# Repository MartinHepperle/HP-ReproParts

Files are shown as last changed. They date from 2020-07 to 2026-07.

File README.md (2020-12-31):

<h1>HP-ReproParts</h1>
<p>This repository collects my 3D printable parts for computers.
The focus is mainly on Hewlett Packard computers.
</p>
<p>Most of these parts have been printed on my low cost hobby printer "Anycubic Mega 3D" in PLA.
Before I owned it, I had sent the STL files to commercial 3D printing services to obtain parts in very good quality and in materials unavailable for hobby printers, e.g. very strong sintered nylon.
</p>

<p>The data is available in binary STL format, which can be used by all commercial printing services.
For your hobby printer you have to process it by your favorite slicing software (e.g. Cura) to produce the required toolpath files in GCODE format with the preferred settings for your printer.
</p>
<p>I have spent a considerable amount of time to create these models and am happy to provide these parts for hobby purposes.
You can use these models for any non-commercial purposes, but not sell the models or parts made from them for profit.
All parts will require some sort of rework and assembly. No batteries included.
I cannot guarantee that these parts are fit for any purpose, so use at your own risk.
These parts were created for replacing broken or missing parts of obsolete computers and peripherals for hobby purposes. They may violate safety regulations and disturb your good taste. Consume with a grain of salt and brain.
</p>

<p>Note to collectors: these parts are different enough from genuine spare parts so that they cannot be mistaken for fakes.
</p>

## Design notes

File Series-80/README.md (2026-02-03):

<h1>Parts for Series-80 Computers (85, 86, 87, 9915)</h1>

<ul>
  <li>Case for interface modules, PRM-85 module or other new developments (what about that new color graphics board you wanted to develop?),</li>
  <li>EPROM-Drawer-Bot and EPROM-Drawer-Top make a module case for a reporduction EPROM drawer, using the slightly modified PCB created by Tony Cox.</li>
  <li>Case for the EBTKS board with two different upper shells - select one according to your taste</li>
  <li>Replacement plungers for Series-80 keyboards (requires UV-resin printer). This model is for the plungers with 4 thin "feet" extending downwards.</li>
</ul>

<h2>Notes</h2>
<p>
I use small M 2.5 screws with threaded brass inserts to close the cases. Metal washers can be glued into the recesses to provide a stronger surface for the screw heads.
Inserts and washers can be glued in with steel filled epoxy in double syringes which gives a stronger and harder bond than the more flexible clear epoxy glues. Ideally, the brass inserts can simply be pressed into the holes without glue and secured with a few drops of superglue.
Self tapping screws do not go well with PLA - maybe you have better luck or use ABS.
</p>
The EPROM-Drawer module case is about 10 mm longer than the standard module case. The reason for this: unfortunately, the PCB layout created by Tony Cox is a bit larger than the original layout and I do not have a possibility to modify it easily.
Also portions of the the side edges of the PCB have to be milled away to make the PCB fit into the module case. All this must be done before placing components on the board, of course.
The openings in the top allow for using standard sockets and also for seeing which EPROMs are installed. The original drawer uses semi-buried sockets which seem to be unobtainium today.
</p>
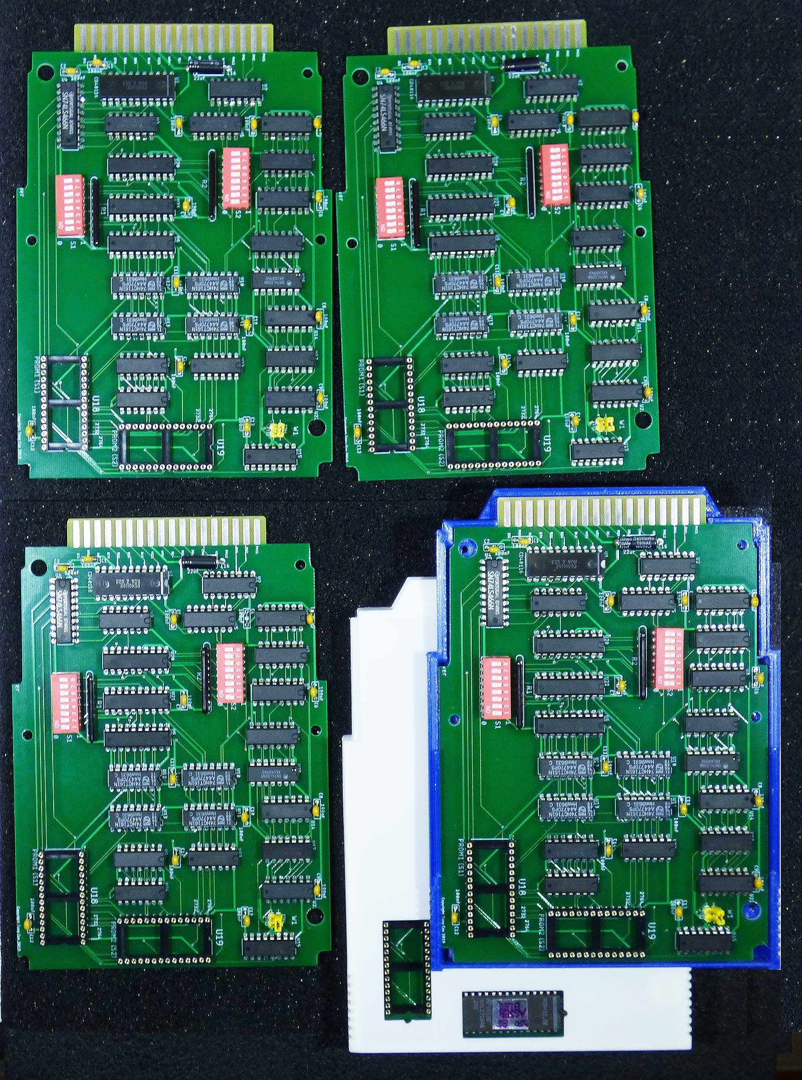
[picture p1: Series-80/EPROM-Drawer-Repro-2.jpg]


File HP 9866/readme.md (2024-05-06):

These models are rear bumpers for the HP 9866 printer and some HP 98x0 computers.

The original parts often become brittle and crumble into pieces.
You can print them in hard PLA or, even better, use a flexible material like TPU (shore 58 or similar).

Printing them "upside down" (with the rim pointing upwards) eliminates the need for support structures.

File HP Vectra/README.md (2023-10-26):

These parts can be used to install a 3.5 inch flexible disk drive into the early HP-Vectra PC drive cage, using sliding side rails.
The small rectangular block can be glued onto the rail with rubber cement, allowing for adjusting the depth position to match the front bezel.
If necessary, it can be broken lose to remove the disk drive.
I also glued strips of cardboard to the side of the rails to achieve smooth motion with a bit of friction.

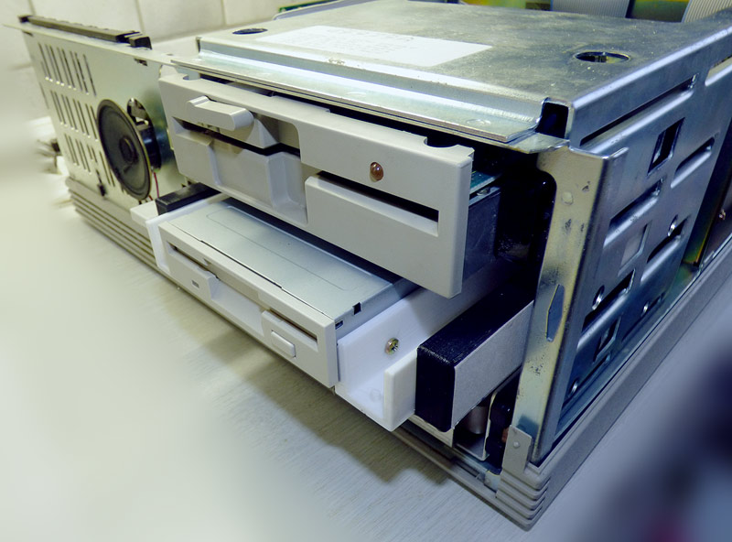
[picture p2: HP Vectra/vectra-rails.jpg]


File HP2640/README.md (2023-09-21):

<h1>Parts for HP Terminals of the 264x Series.</h1>
<ul>
  <li>cover for keyboard switches</li>
  <li>cable hood for the serial interface cable</li>
</ul>

<h2>Cable Hoods:</h2>
I usually glue the cables into these hoods after testing them, because screws do not hold well in the relatively soft PLA material.
Also, it is simple to make another one, if needed. 
For the cables I often use ready made serial or parallel printer cables with 25 or 36 wires and replace the connectors.
This is cheaper than buying cable by the meter and one connector is already in place.

<h2>HP 2640 Keyboard Cover</h2>
When printed in PLA, the nose of the retention clip may break if it is bent too much. 
Use a file or sharp knife to shorten it so that the cover is held in place without overstressing the part.
If the clip breaks, cyanacrylate superglue may be your friend.

<h2>Color</h2>
I printed the cover in white and painted it later.
The keyboard cover can be painted with plastic model paint like Testors, Revell or what else. 
They offer many gray/tan tones to match your more or less yellowed keyboard.

<h2>Surface Quality</h2>
3D printing usually leaves a fine structure on the surface. You may want to experiment with layer thickness and extruder temperature.
If you are a perfectionist, you can apply multiply cycles of polyester putty or spray-on filler followed by wet sanding to create a smooth surface.
When printing in ABS, it might be possible to smooth the surface and close tiny gaps by applying acetone, but this is a bit on the risky side of life.

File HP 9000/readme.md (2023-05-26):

HP 9836 color monitor cable hood
================================
For building a replacement for the monitor cable I used a VGA cable with shielded R, G, B wires and these shells.
After testing, both halves were simply glued together.

HP 9000 DIO Board Lever
=======================
Suitable for do-it your self DIO-I boards or for replacing broken handles.

HP 9836 monitor locking plate handle
====================================
The HP 9836 monitor is locked to the computer case by a sliding aluminum plate with two square plastic handles.
The material of these handles becomes brittle and often their corners break, leaving only ugly fragments of the handles.
You can remove the nickel plated brass rivets after thinning their hollow ends by drilling with a 5-6 mm drill bit to about 1 mm depth.
This just removes part of the widened end so that the rivets can be pushed out, e.g. with a 3 mm steel pin and a hammer.
Then you can mount the new handles and install the rivets again simply by pressing them in using a vise.
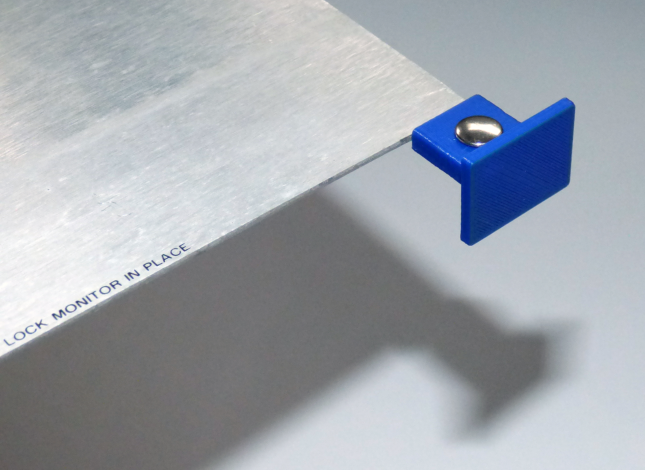
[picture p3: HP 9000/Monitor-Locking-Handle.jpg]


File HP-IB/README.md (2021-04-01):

<h1>Parts for HP-IB Devices</h1>
<ul>
<li>Case for the HP85Disk PCB</li>
</ul>

<em>The HP-logo was created with a vinyl cutter which was found on the curb. 
  Only the repair of the broken power connector and a set of new knifes was necessary. Plus some investigation about the almost forgotten Houston Instruments DMPL plotter language to make it useful again...</em>

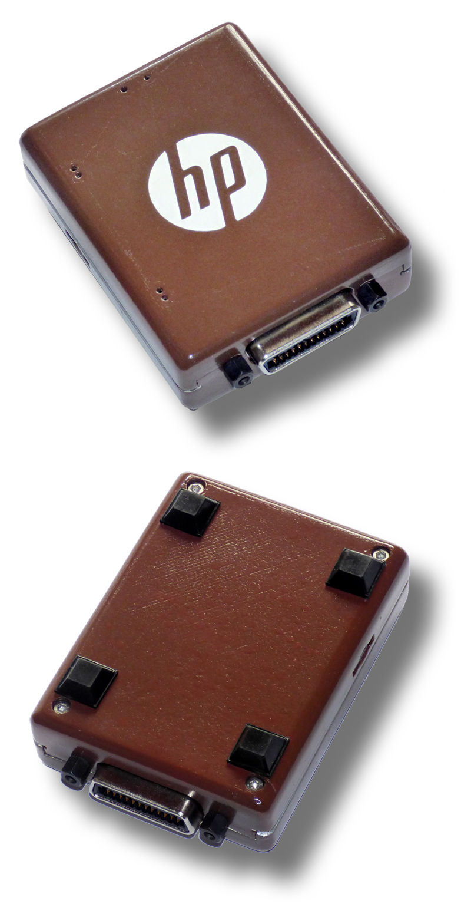
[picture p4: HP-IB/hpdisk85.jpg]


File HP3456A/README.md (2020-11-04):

Often you receive test equipment without the mounting brackets ("ears"). These can be found on E-Bay, but here in Europe they are rarely offered.
Therefore I tried to make my own replacements.

I have used them for mounting some HP test equipment, like the 3456A voltmeters in a small 19" rack.
All parts are massive (i.e. no hollow internal structure) to provide sufficient strength, thus take about 4-5 hours to print on a hobby printer.
You should check whether the weight of your device can be properly supported.
Often it may be better to produce similar parts from sheet metal or "L"-type bar stock.

The front brackets will suit many other HP devices. I did not bother to add handles to these parts.

The rear brackets were needed to support the deep boxes, which overhang the rear end of my short rack.
They are probably not useful for other applications.

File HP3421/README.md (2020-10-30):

<h1>Parts for the HP 3421 Data Acqusition System</h1>
<ul>
  <li>rear cover</li>
  <li>cable strain relief clamp</li>
</ul>
Both are held in place by M3 screws (cover: 10 mm, clamp: 16 mm). A strip of foam should be glued to the cover so that the wires are pressed into the foam by the ridge on the clamp.

These data acqusition systems have 3 slots for plug-in boards and sometimes the covers and cable clamps are missing.
Note that some boards also use specific screw terminal blocks (e.g. the relais multiplexer) while others use simpe edge connectors (the digital I/O board). I do not have a solution for these missing terninal blocks.

<image src="https://github.com/MartinHepperle/HP-ReproParts/blob/master/HP3421/HP-3421-cover-and-clamp.jpg"></image>

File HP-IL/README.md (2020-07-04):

<h1>Parts for the HP-IL Loop</h1>

<ul>
<li>Individual connectors for creating cables</li>
<li>Twin connector pair for building into devices</li>
</ul>
The "joined" parts are several small parts joined by spruces to form a single part. 
Many commercial 3D print services do not handle a set of small parts - they want a single part to simplify handling.

<p>
  Note that manufacturing these small connectors requires more parts (connector pins) and some delicate assembly work.
  More details can be found on https://www.MH-AeroTools.de/hp.  
  </p>

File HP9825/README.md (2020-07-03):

<h1>Parts for the HP 9825 Desktop Calculator</h1>
<ul>
  <li>ROM module case.</li>
  <li>rear cover (may need some metalwork to replace fine nose at bottom.</li>
</ul>

These parts can be used to build a case for a custom ROM or ROM replacement board.

The rear cover must be glued or riveted together and some fine tuning will be necessary to make the retention clip fit into the case. Maybe a small metal or hard plastic strip should be added to make it fit into the thin slot in the foam plastic case of the 9825.

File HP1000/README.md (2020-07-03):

<h1>Parts for HP 1000 Computer Systems</h1>

<ul>
  <li>edge connector hoods for different connector types</li>
</ul>

These were made for hooking up cables to I/O boards of the HP 1000 A-Series.

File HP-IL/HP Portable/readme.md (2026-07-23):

These files demonstrate how to use the HP-IL interface of the HP 110 and the Portable Plus from Microsoft BASIC.
The module works with the ROM-based BASIC interpreter and should also be usable with the disk-based GWBASIC interpreter for the HP Portable.
A binary module with several functions is loaded and can be used to interact with HP-IL devices on the loop.

Assemble on a PC with e.g. DOS-BOX
--------------------
The assembler source in HPIL.ASM can be assembled with a batch file like GO.BAT and the resulting binary file can be converted into a BASIC program (in ASCII format) by using the Python script BINtoHEX.py.
This script creates code to load the binary from DATA statements and appends an example program for talking to a digital voltmeter. The loader also saves the machine code as a binary file which can later be loaded with BLOAD to speed the loading proces up.

Transfer to the Portable
--------------------
For transferring the ASCII file to the portable a serial interface and the bult in or one of the ROM-based terminal programs can be used.

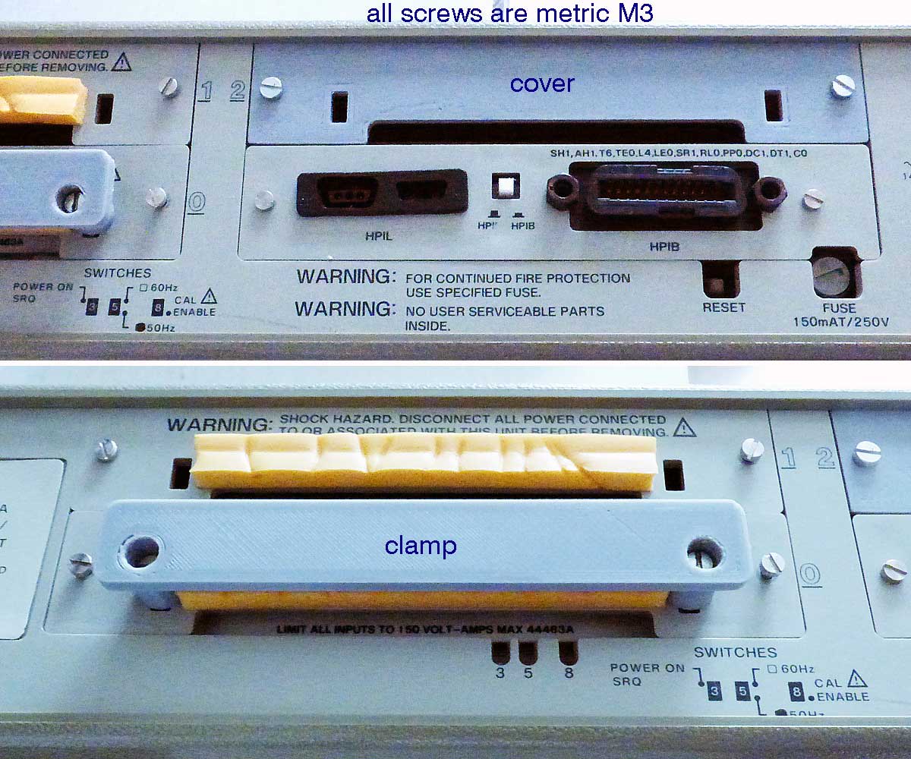
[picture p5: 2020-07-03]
HP3421/HP-3421-cover-and-clamp.jpg

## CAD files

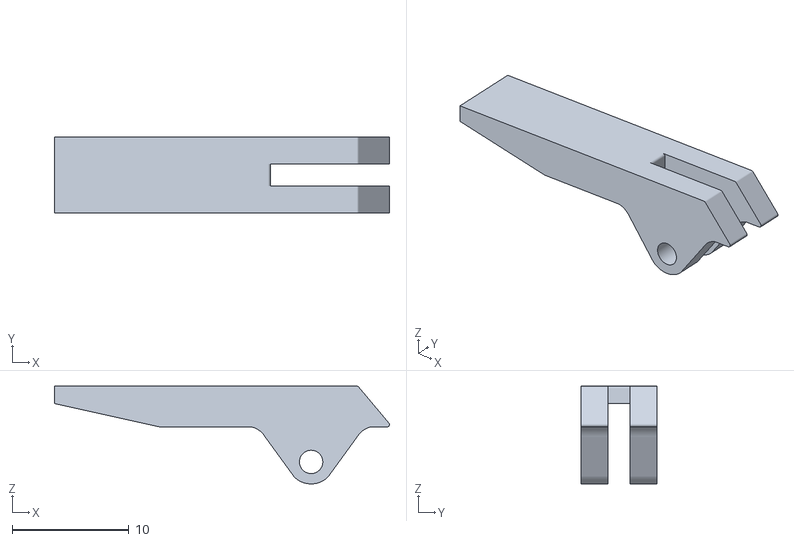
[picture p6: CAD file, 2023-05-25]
HP 9000/HP-9000-Lever.stl
28.7 x 6.50 x 8.39

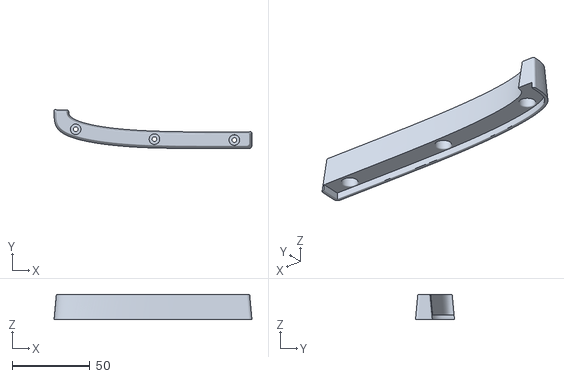
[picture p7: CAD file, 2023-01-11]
HP 9866/HP-0966-Bumper-L.stl
127.7 x 25.2 x 16.4

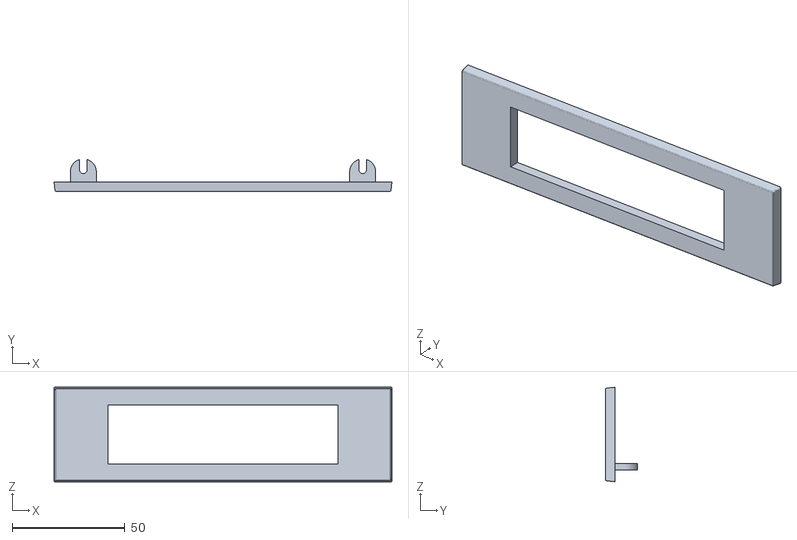
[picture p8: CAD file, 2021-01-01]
HP Vectra/Vectra-Rails-3.stl
150.0 x 14.2 x 42.0

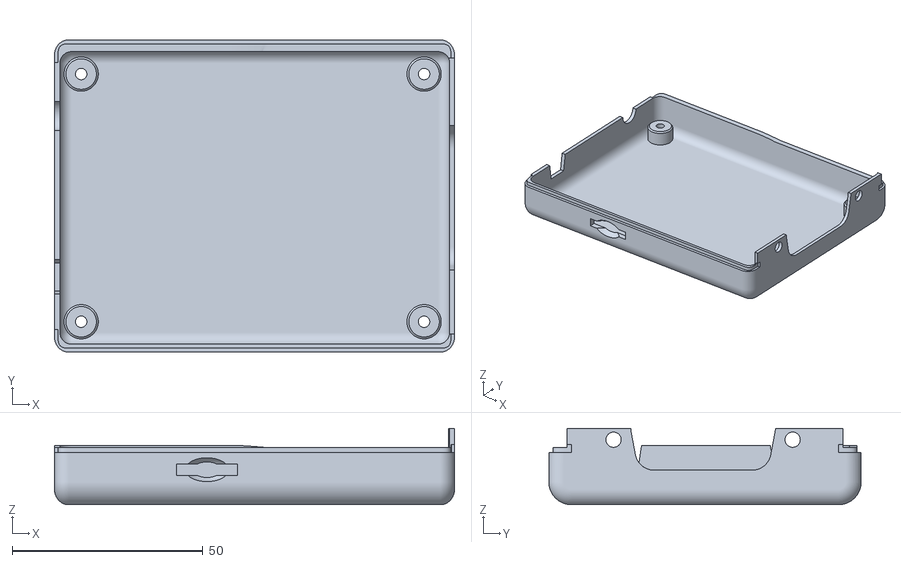
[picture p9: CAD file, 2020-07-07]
HP-IB/hp85disk-bottom.stl
105.0 x 82.0 x 20.1

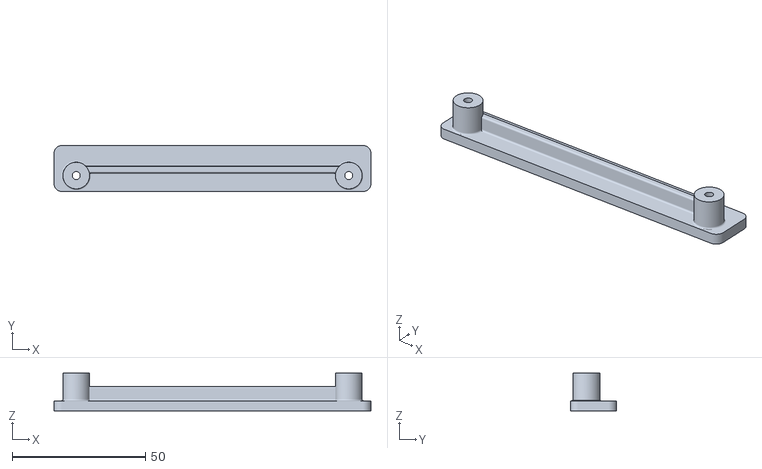
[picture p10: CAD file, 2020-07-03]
HP3421/3421-Clamp.stl
119.0 x 17.3 x 14.2

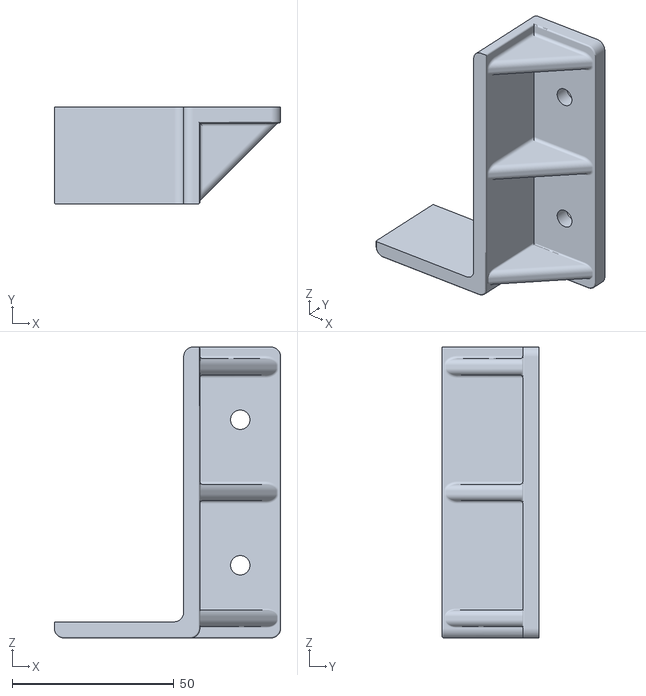
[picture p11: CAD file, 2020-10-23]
HP3456A/3456A-RightRear.stl
70.0 x 30.0 x 90.0

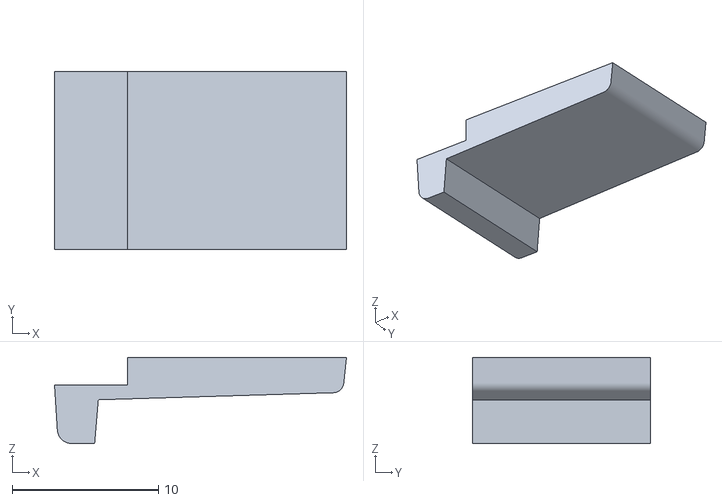
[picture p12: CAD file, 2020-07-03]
HP9825/9825-cover-2.stl
20.0 x 12.2 x 5.90

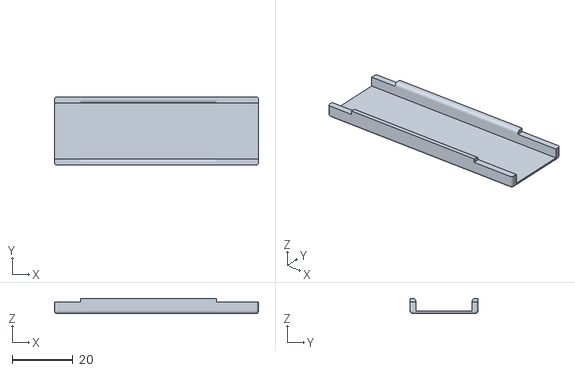
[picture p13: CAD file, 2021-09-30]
Series-80/EBTKS-hood.stl
67.2 x 22.5 x 5.00

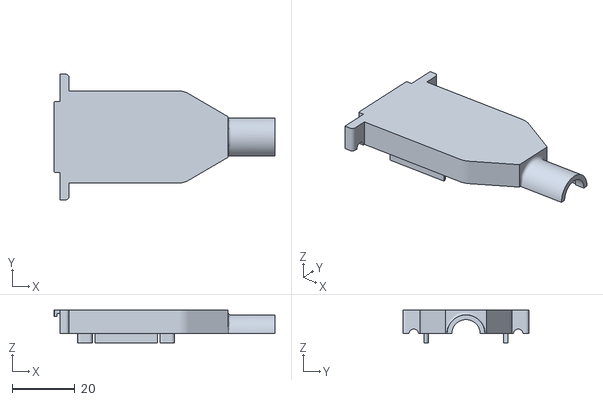
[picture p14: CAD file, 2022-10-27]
HP 9000/HP9836-DB-15-Monitor-Cable-Hood.stl
70.4 x 40.0 x 10.4

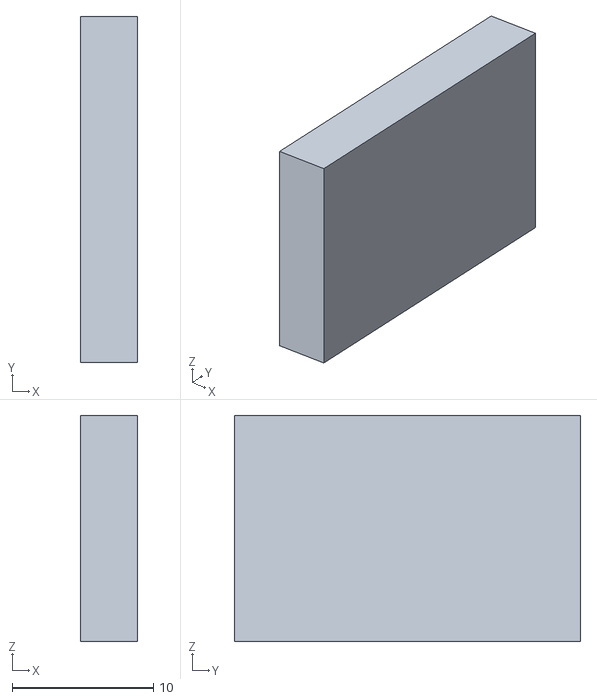
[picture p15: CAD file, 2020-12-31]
HP Vectra/Vectra-Rails-4.stl
4.00 x 24.5 x 16.0

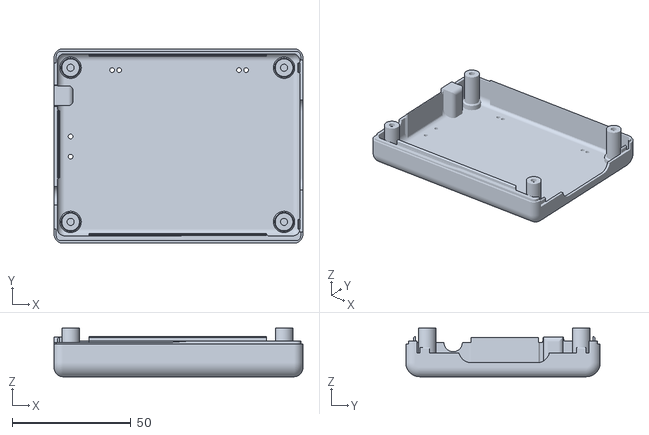
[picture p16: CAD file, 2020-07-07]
HP-IB/hp85disk-top.stl
105.0 x 82.0 x 20.5

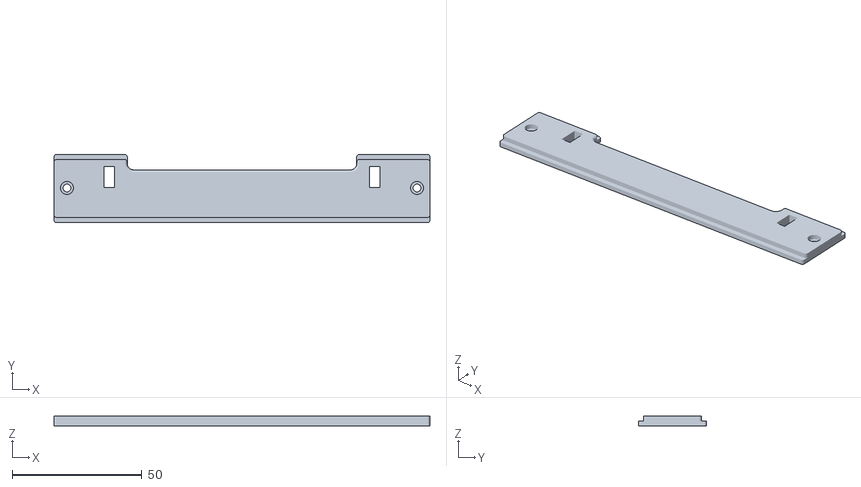
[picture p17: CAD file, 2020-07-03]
HP3421/3421-Cover.stl
145.0 x 26.4 x 3.70

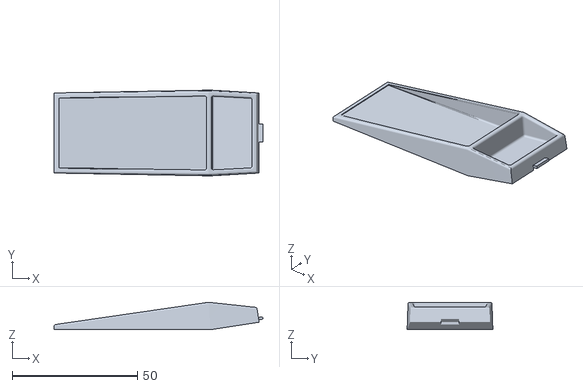
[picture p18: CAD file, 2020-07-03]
HP9825/9825-cover-1.stl
83.5 x 34.3 x 11.0

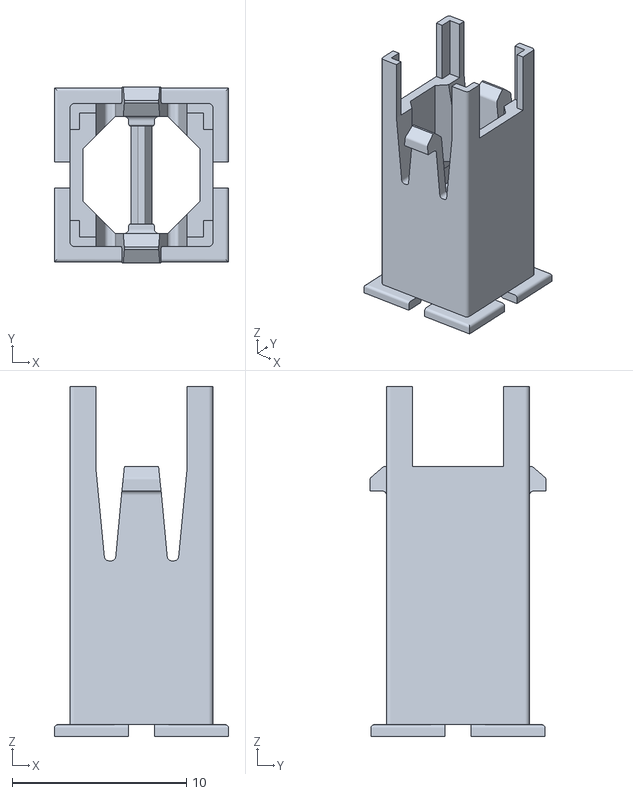
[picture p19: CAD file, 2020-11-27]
Series-80/S80-KBDPlunger.stl
10.0 x 10.1 x 20.1

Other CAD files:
HP 9866/HP-0966-Bumper-R.stl
HP3456A/3456A-LeftRear.stl
HP 9000/HP-9836-Handle.stl
HP3456A/3456A-FrontBracket.stl
HP9825/9825-case-bot.stl
HP9825/9825-case-top.stl

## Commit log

2020-07-03 Add files via upload
    Rear cover (light gray) and cable clamp (black).
    These parts for the rear of the HP 3421 Data Acquisition system. These versatile systems have the same A/D core as the 3668/3478 DVMs and came with HP-IL and (optional) HP-IB interfaces.
    [3421-Clamp.stl, 3421-Cover.stl]
2020-07-03 Add files via upload
    a module case for HP 9825 desktop calculator - top shell
    [9825-case-top.stl]
2020-07-03 Add files via upload
    lower shell
    [9825-case-bot.stl]
2020-07-03 rear cover for HP 9825 desktop calculator
    glue or rivet together
    [9825-cover-1.stl]
2020-07-03 initial upload
    [3421-Cover.stl]
2020-07-12 image inserted
2020-11-27 initial upload
    The keyboards of many Series-80 computers suffer from splitting plungers.
    This model can bes used to print a replacement plunger for one of the several variations of these pungers.
    In contrast to other models floating around, the reinforcement on the top edge is broken in the moddle of each edge.
    This allows pressing the key cap down into the plunger to the same height as the original part.
    Thus the key is level with its neighboring keys.
    The required low wall thickness and smooth surface finish require that this part is printed with a resin printer - a normal additive printer will not produce useable results.
    The resin parts are more brittle than e.g. PLA or ABS p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
    [S80-KBDPlunger.stl]
2021-04-08 Add files via upload
    Added centering ribs/pockets for easier assembly.
2021-04-08 Added centering ribs/pockets for easier assembly.
2021-09-30 Add files via upload
    Two variants of a case for the EBTKS board.
    If you need the USB connector, you can cut a slot for the plug and glue a piece of sheet material into the cover to leave a shallow recess for the USB plug.
    [EBTKS-hood.stl]
2022-10-27 Add files via upload
    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
    [HP9836-DB-15-Monitor-Cable-Hood.stl]
2023-01-11 Create readme.md
    A set of rear bumpers for the HP 9866 printer (and similar devices?)
2023-05-25 initial creation
    A lever for HP-9000 DIO-I boards.
    [HP-9000-Lever.stl]
